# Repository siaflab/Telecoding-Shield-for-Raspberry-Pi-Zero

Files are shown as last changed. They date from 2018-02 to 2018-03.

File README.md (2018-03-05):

# Telecoding-Shield-for-Raspberry-Pi-Zero
Telecoding Shield for Raspberry Pi Zero is a board that can mount 920 MHz band LoRa module, OSD and DAC chip.
Power supply to Raspberry Pi Zero can also be done from this shield in the range of 5V to 14V.
If you change the grade of the DC - DC converter, such as changing from Murata's "OKL-T/3-W12N-C" to "OKL-T/6-W12N-C", 
you can select the current value required for your system. The current can be supplied up to 6 A, it is possible to operate rasberry pi 3.
This Shield successfully communicated between the ground and the stratosphere in our <a href="http://space-moere.org">project</a>.

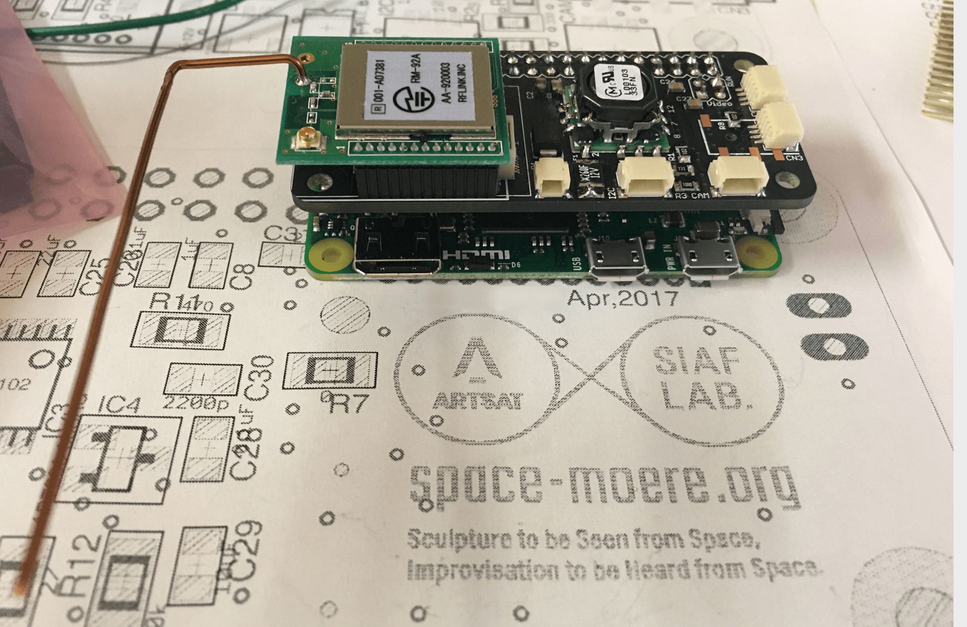
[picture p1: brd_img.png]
brd_img


## REQUIREMENT
- raspberry pi zero

## DEPENDENCIES
- OSD chip: [MAX7456](https://datasheets.maximintegrated.com/en/ds/MAX7456.pdf)
- DAC chip: [PCM5102](http://masterandrey.com/files/pcm5102.pdf)

This board can mount either of the following LoRa modules.
The frequency with LoRa's unlicensed band can communicate varies depending on the country's rule.
- [interplan IM920C](http://www.interplan.co.jp)
- [rflink RM-92A](http://www.rflink.co.jp/)

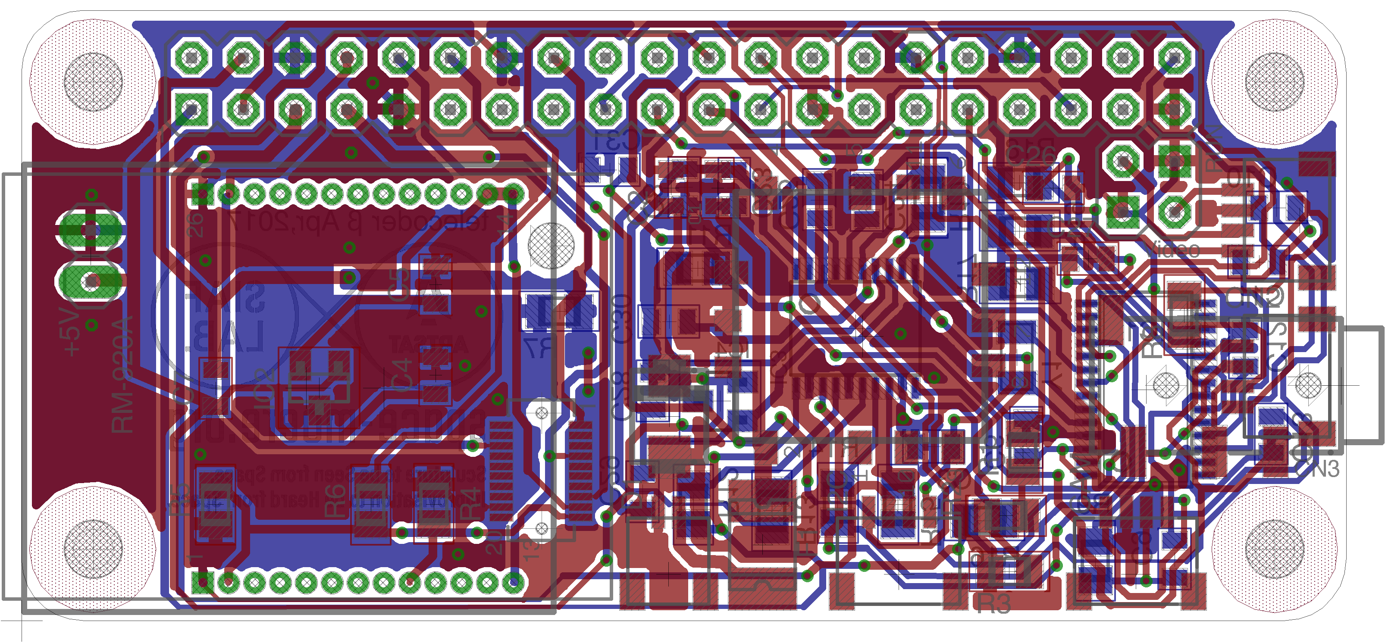
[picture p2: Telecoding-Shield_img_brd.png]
Telecoding-Shield_img_brd

Refer to the <a href="https://www.homepage-tukurikata.com/">partslist</a> for other mounting parts.

## CREDIT
Telecoding Shield for Raspberry Pi Zero licensed under MIT License.  
https://github.com/siaflab/Telecoding-Shield-for-Raspberry-Pi-Zero

Space Moere Project  
ARTSAT x SIAF Lab  
http://space-moere.org

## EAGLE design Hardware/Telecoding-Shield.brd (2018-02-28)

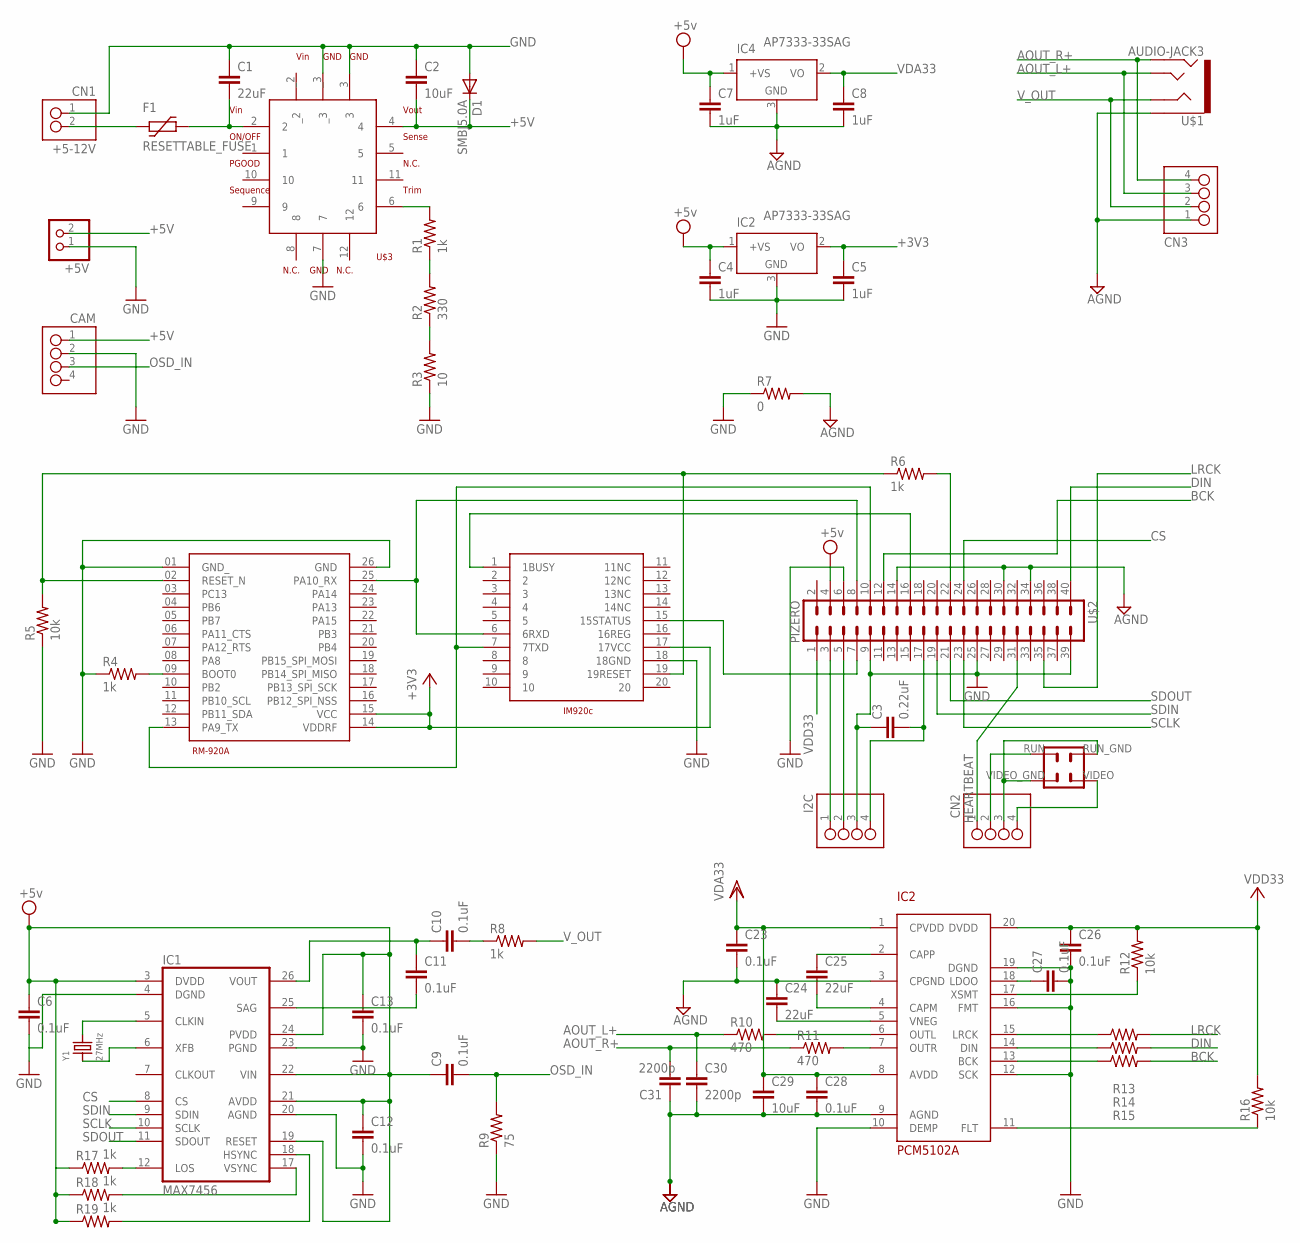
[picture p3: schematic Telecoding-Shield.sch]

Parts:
+5V: PINHD-1X2; 1X02
C1, C24, C25: 22uF; 0805
C2, C29: 10uF; 0805
C3: 0.22uF; 0805
C4, C5, C7, C8: 1uF; 0805
C6, C9, C10, C11, C12, C13, C23, C26, C27, C28: 0.1uF; 0805
C30, C31: 2200p; 0805
CAM: SM04B-SRSS-TB
CN1: +5-12V; SM02B-SRSS-TB
CN2, CN3: SM04B-SRSS-TB
D1: SMBJ5.0A; SMA
F1: RESETTABLE_FUSE; 1812L
I2C: SM04B-SRSS-TB
IC1: MAX7456; TSSOP28
IC2, IC4: AP7333-33SAG; SOT23
IC3: PCM5102; TSSOP20
R1, R4, R6, R8, R17, R18, R19: 1k; M0805
R2: 330; M0805
R3: 10; M0805
R5, R12, R16: 10k; M0805
R7: 0; M0805
R9: 75; M0805
R10, R11: 470; M0805
R13, R14, R15: 27; M0805
RM-920A: RM-92A_SOCKETBP; RM-92A
U$1: AUDIO-JACK3; AUDIO-JACK-TRRS-SMD
U$2: PIZERO; PIZERO_THOUGH_HOLE
U$3: MURATA_OKL_T6_W12
U$7: IM920C
Y1: 27MHz; ABS07

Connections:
+3V3: C5.1, IC2.2 (VO), RM-920A.14 (VDDRF), RM-920A.15 (VCC), U$7.17 (17VCC)
+5V: +5V.2, C2.2, C4.1, C6.1, C7.1, C9.1, C12.1, C13.1, CAM.1, D1.C, IC1.3 (DVDD), IC1.19 (RESET), IC1.21 (AVDD), IC1.22 (VIN), IC1.24 (PVDD), IC2.1 (+VS), IC4.1 (+VS), R17.1, R18.1, R19.1, U$2.4, U$3.4
AGND: C7.2, C8.2, C23.2, C24.1, C28.2, C29.2, C30.2, C31.1, CN3.1, IC3.3 (CPGND), IC3.9 (AGND), IC4.3 (GND), R7.2, U$1.EARTH, U$2.14, U$2.30, U$2.34, U$3.7
AOUT_L+: C30.1, CN3.3, R10.1, U$1.TIP
AOUT_R+: C31.2, CN3.4, R11.1, U$1.RING2
BCK: R15.2, U$2.12
CS: IC1.8 (CS), U$2.24
DIN: R14.2, U$2.40
GND: +5V.1, C1.1, C2.1, C3.1, C4.2, C5.2, C6.2, C12.2, C13.2, C26.2, C27.2, CAM.2, CN1.1, CN2.3, D1.A, I2C.3, IC1.4 (DGND), IC1.20 (AGND), IC1.23 (PGND), IC2.3 (GND), IC3.10 (DEMP), IC3.12 (SCK), IC3.16 (FMT), IC3.19 (DGND), R3.1, R4.1, R5.1, R7.1, R9.1, RM-920A.01 (GND_), RM-920A.26 (GND), U$2.6, U$2.9, U$2.25, U$2.39, U$2.RUN_GND, U$2.VIDEO_GND (VIDEOP_GND), U$3.3, U$3._3, U$7.18 (18GND)
HEARTBEAT: CN2.1, U$2.31
LRCK: R13.2, U$2.35
unnamed: R5.2, R6.1, RM-920A.02 (RESET_N), U$7.19 (19RESET)
unnamed: C1.2, F1.2, U$3.2
unnamed: R6.2, U$2.22
unnamed: RM-920A.25 (PA10_RX), U$2.8, U$7.6 (6RXD)
unnamed: R4.2, RM-920A.09 (BOOT0)
unnamed: R2.1, R3.2
unnamed: U$2.7, U$7.15 (15STATUS)
unnamed: U$2.16, U$7.1 (1BUSY)
unnamed: R1.1, R2.2
unnamed: R1.2, U$3.6
unnamed: CN2.4, U$2.VIDEO
unnamed: IC1.5 (CLKIN), Y1.2
unnamed: RM-920A.13 (PA9_TX), U$2.10, U$7.7 (7TXD)
unnamed: CN1.2, F1.1
unnamed: IC1.6 (XFB), Y1.1
unnamed: IC1.12 (LOS), R17.2
unnamed: IC1.17 (VSYNC), R18.2
unnamed: IC1.18 (HSYNC), R19.2
unnamed: I2C.1, U$2.3
unnamed: I2C.2, U$2.5
unnamed: C3.2, I2C.4, U$2.17
unnamed: CN2.2, U$2.RUN
unnamed: C10.1, C11.1, IC1.26 (VOUT)
unnamed: C10.2, R8.1
unnamed: C11.2, IC1.25 (SAG)
unnamed: C24.2, IC3.5 (VNEG)
unnamed: C25.1, IC3.2 (CAPP)
unnamed: C25.2, IC3.4 (CAPM)
unnamed: C27.1, IC3.18 (LDOO)
unnamed: IC3.7 (OUTR), R11.2
unnamed: IC3.15 (LRCK), R13.1
unnamed: IC3.6 (OUTL), R10.2
unnamed: IC3.14 (DIN), R14.1
unnamed: IC3.13 (BCK), R15.1
unnamed: IC3.11 (FLT), R16.1
unnamed: IC3.17 (XSMT), R12.1
OSD_IN: C9.2, CAM.3, R9.2
SCLK: IC1.10 (SCLK), U$2.23
SDIN: IC1.9 (SDIN), U$2.19
SDOUT: IC1.11 (SDOUT), U$2.21
VDA33: C8.1, C23.1, C28.1, C29.1, IC3.1 (CPVDD), IC3.8 (AVDD), IC4.2 (VO)
VDD33: C26.1, IC3.20 (DVDD), R12.2, R16.2, U$2.1
V_OUT: CN3.2, R8.2, U$1.RING1

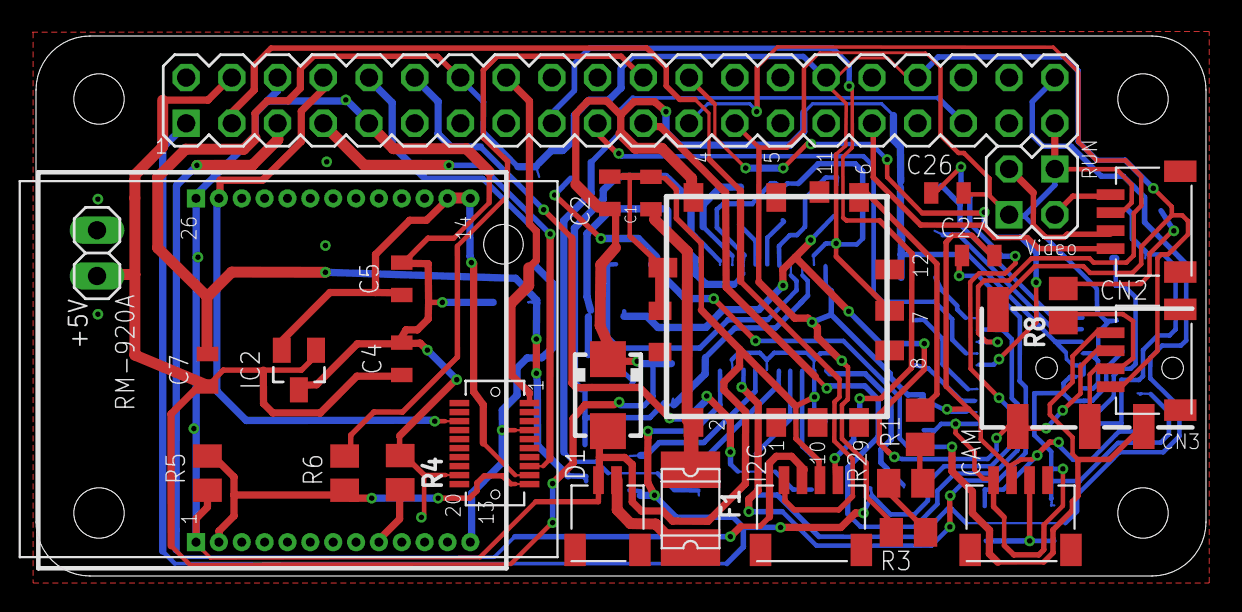
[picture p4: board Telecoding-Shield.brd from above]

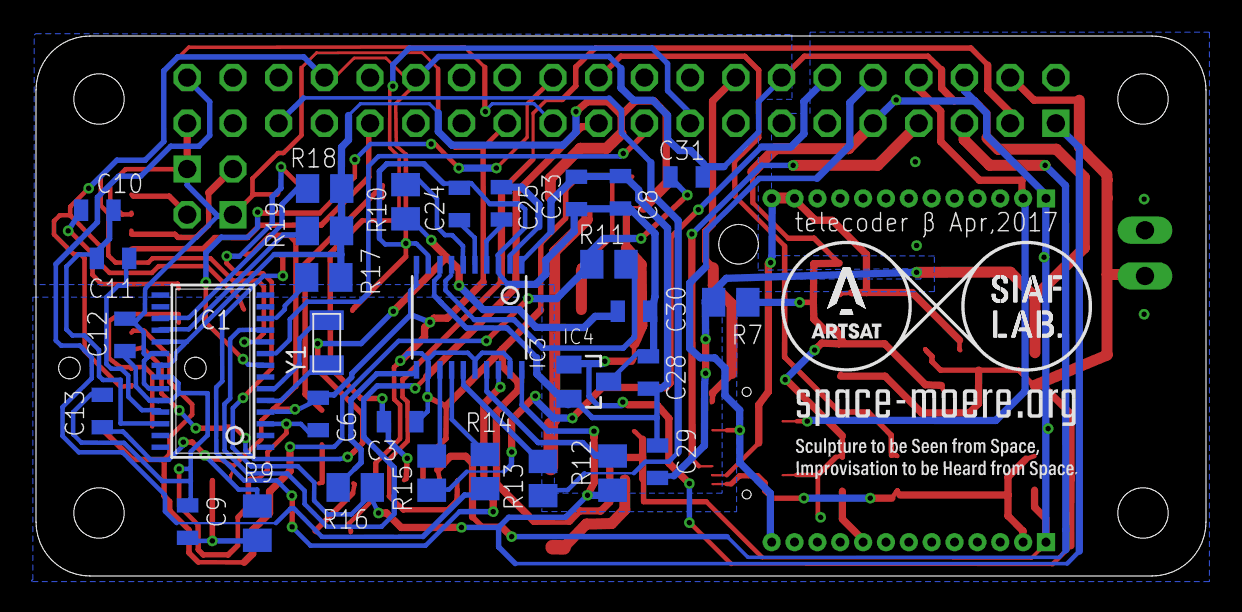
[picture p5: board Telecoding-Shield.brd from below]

Board: 2 copper layers, 65.0 x 30.0 mm, 59 parts (31 on the bottom side), 54 nets.

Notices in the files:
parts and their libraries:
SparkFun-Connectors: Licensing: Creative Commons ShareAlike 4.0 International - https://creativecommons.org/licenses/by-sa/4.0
